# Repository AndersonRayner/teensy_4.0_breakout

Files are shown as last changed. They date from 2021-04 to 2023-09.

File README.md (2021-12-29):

# Teensy 4.0 Breakout
Breakout Board for the Teensy 4.0. The connectors are designed to match the Pixhawk standard connectors, making it easy to interface with different sensors.

Features:
- 6 - 36 V Input
- 2 x Serial ports
- 1 x SPI with 2x CS
- 2 x I2C Ports
- 3 x PWM / ADC

<p align="center">
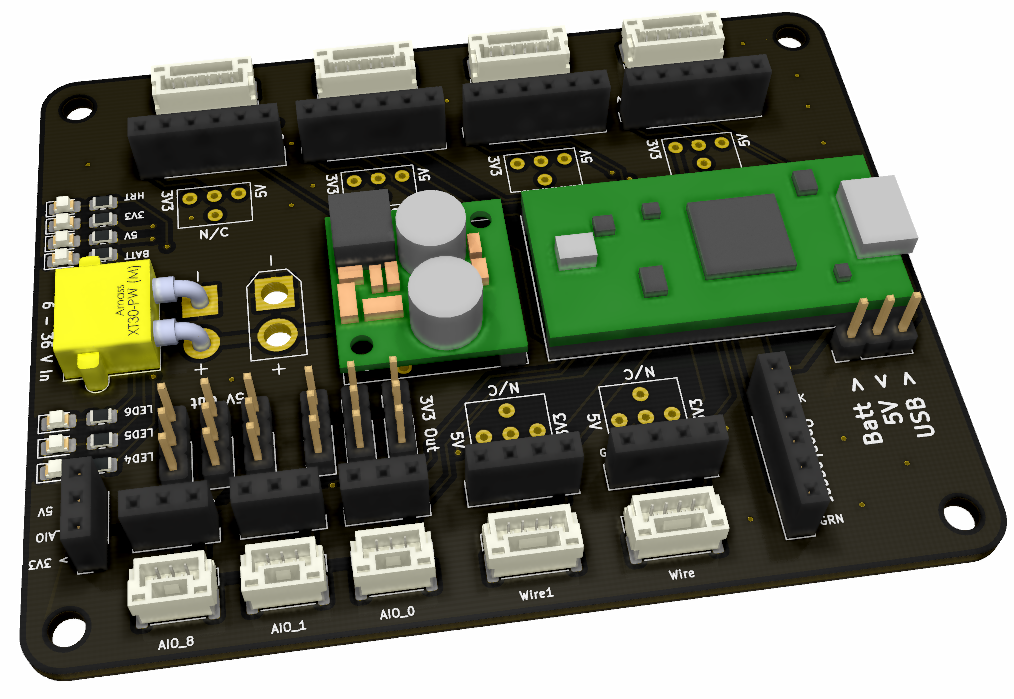
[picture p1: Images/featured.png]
  
</p>

Make sure to clone recursively!
```
git clone https://github.com/AndersonRayner/teensy_4.0_breakout.git --recursive
```

## Usage
- As the connectors are matching the Pixhawk standard, using the 0.1" headers means you can reverse plug! 
- Power for each of the output rails can be selected using the jumpers (between 3V3 and 5V)

## Contributions
As always, PRs are welcome!

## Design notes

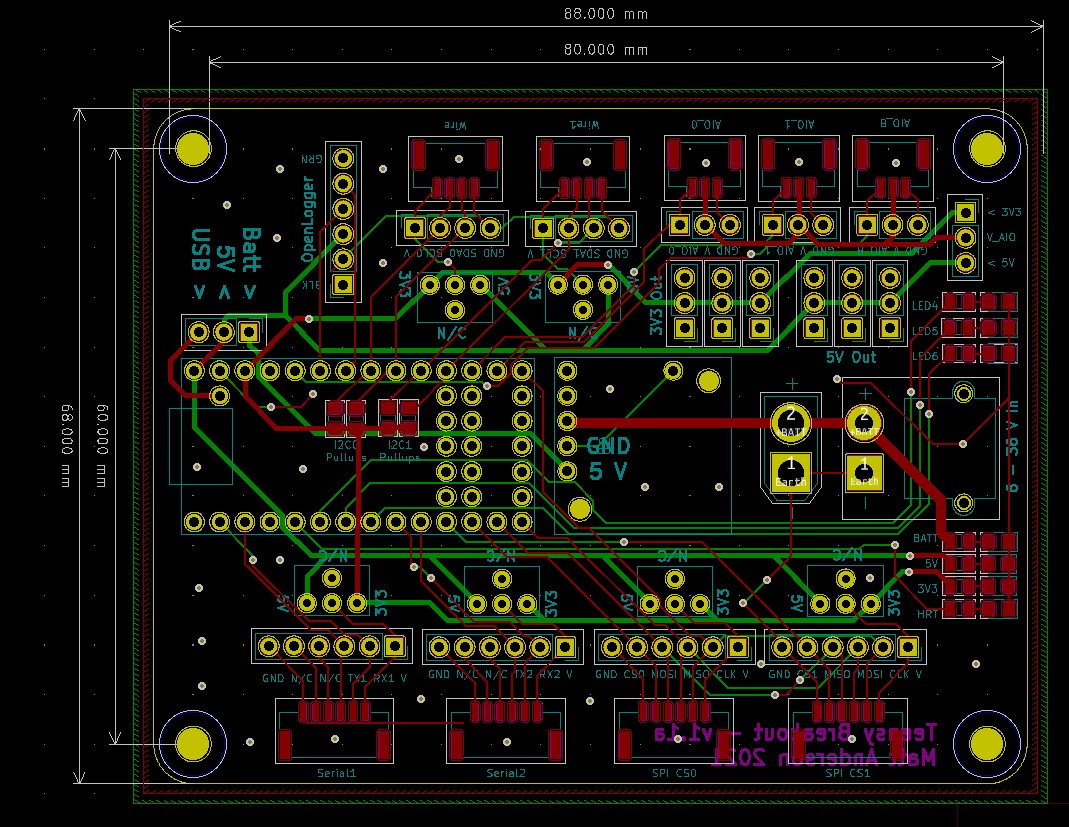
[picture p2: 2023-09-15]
PCB/schematics/pcb.jpg

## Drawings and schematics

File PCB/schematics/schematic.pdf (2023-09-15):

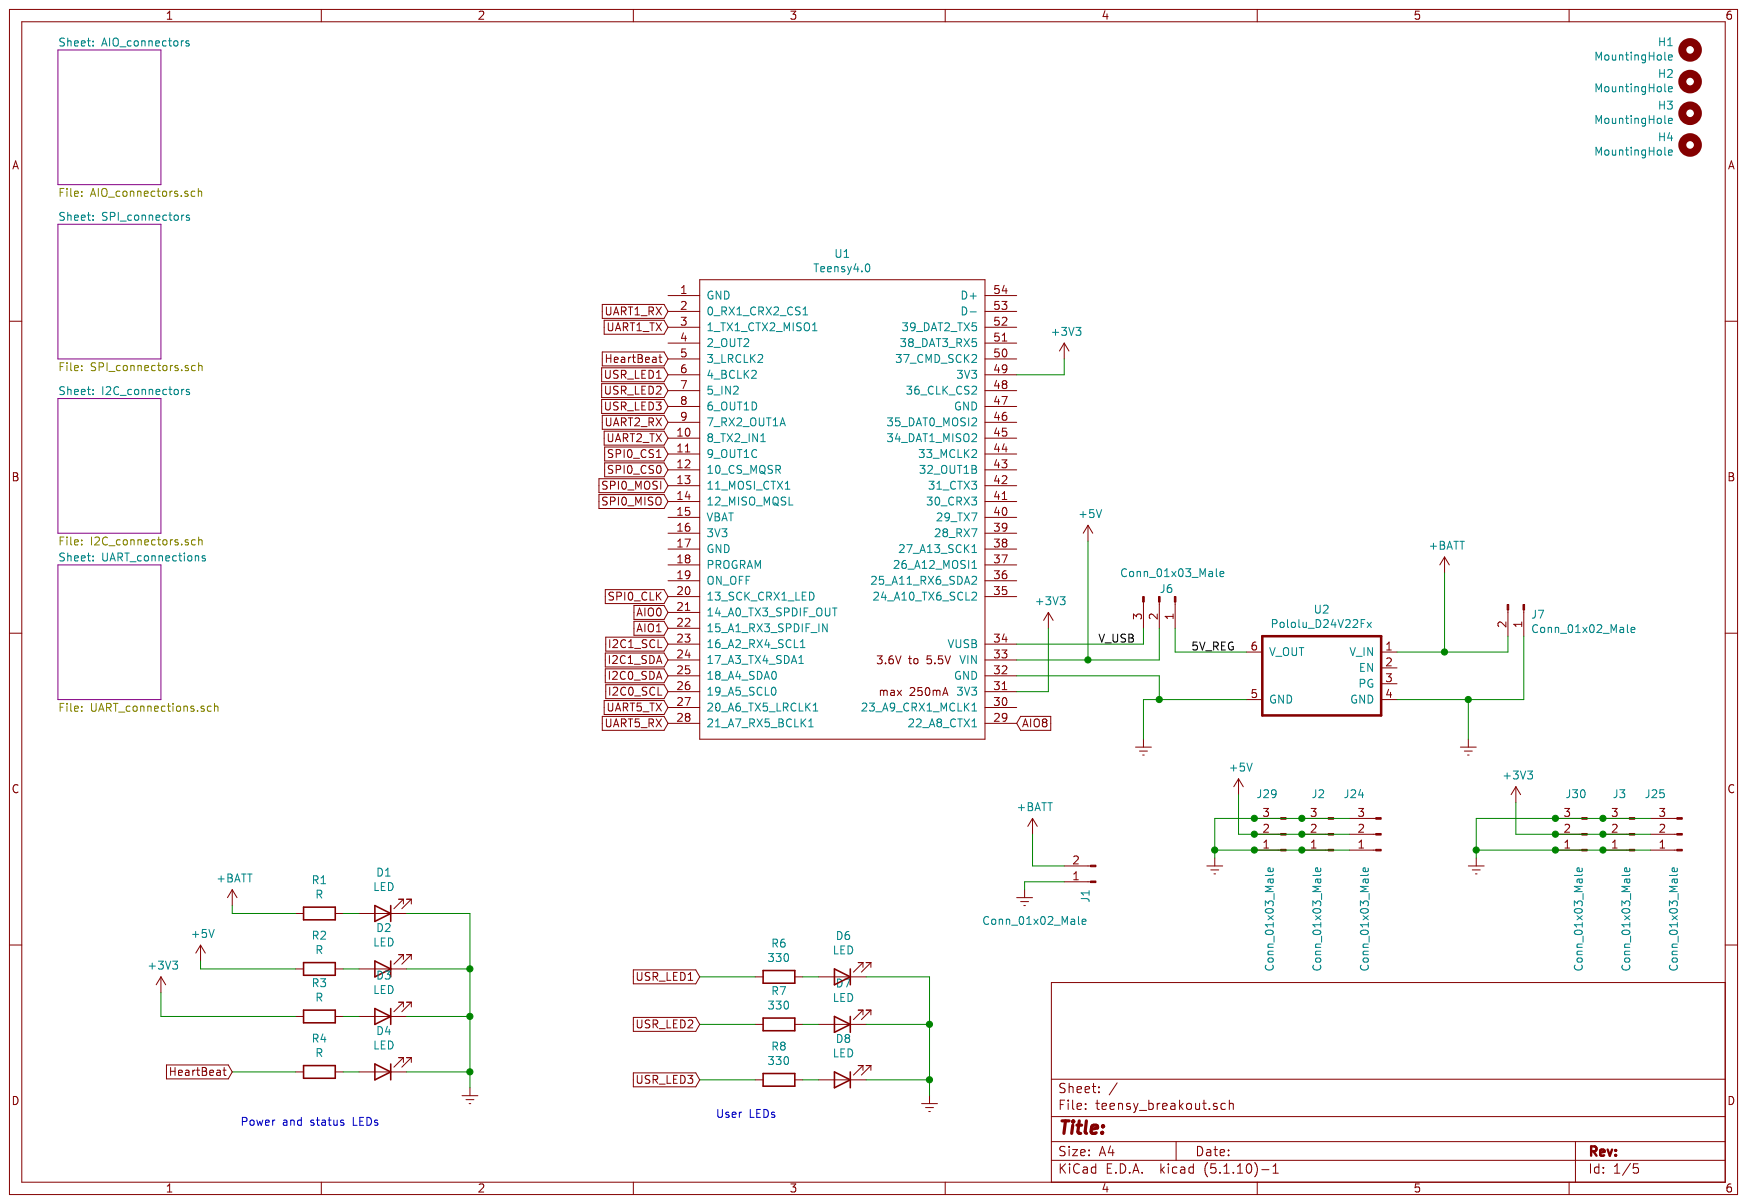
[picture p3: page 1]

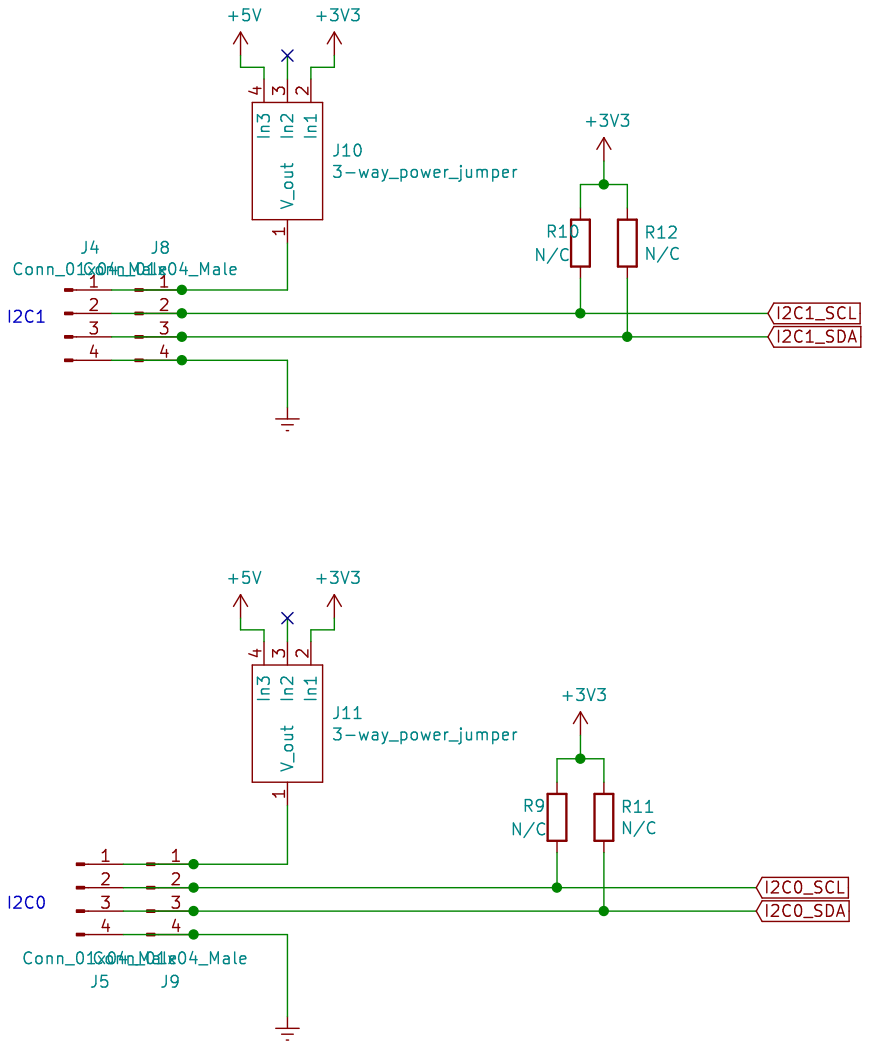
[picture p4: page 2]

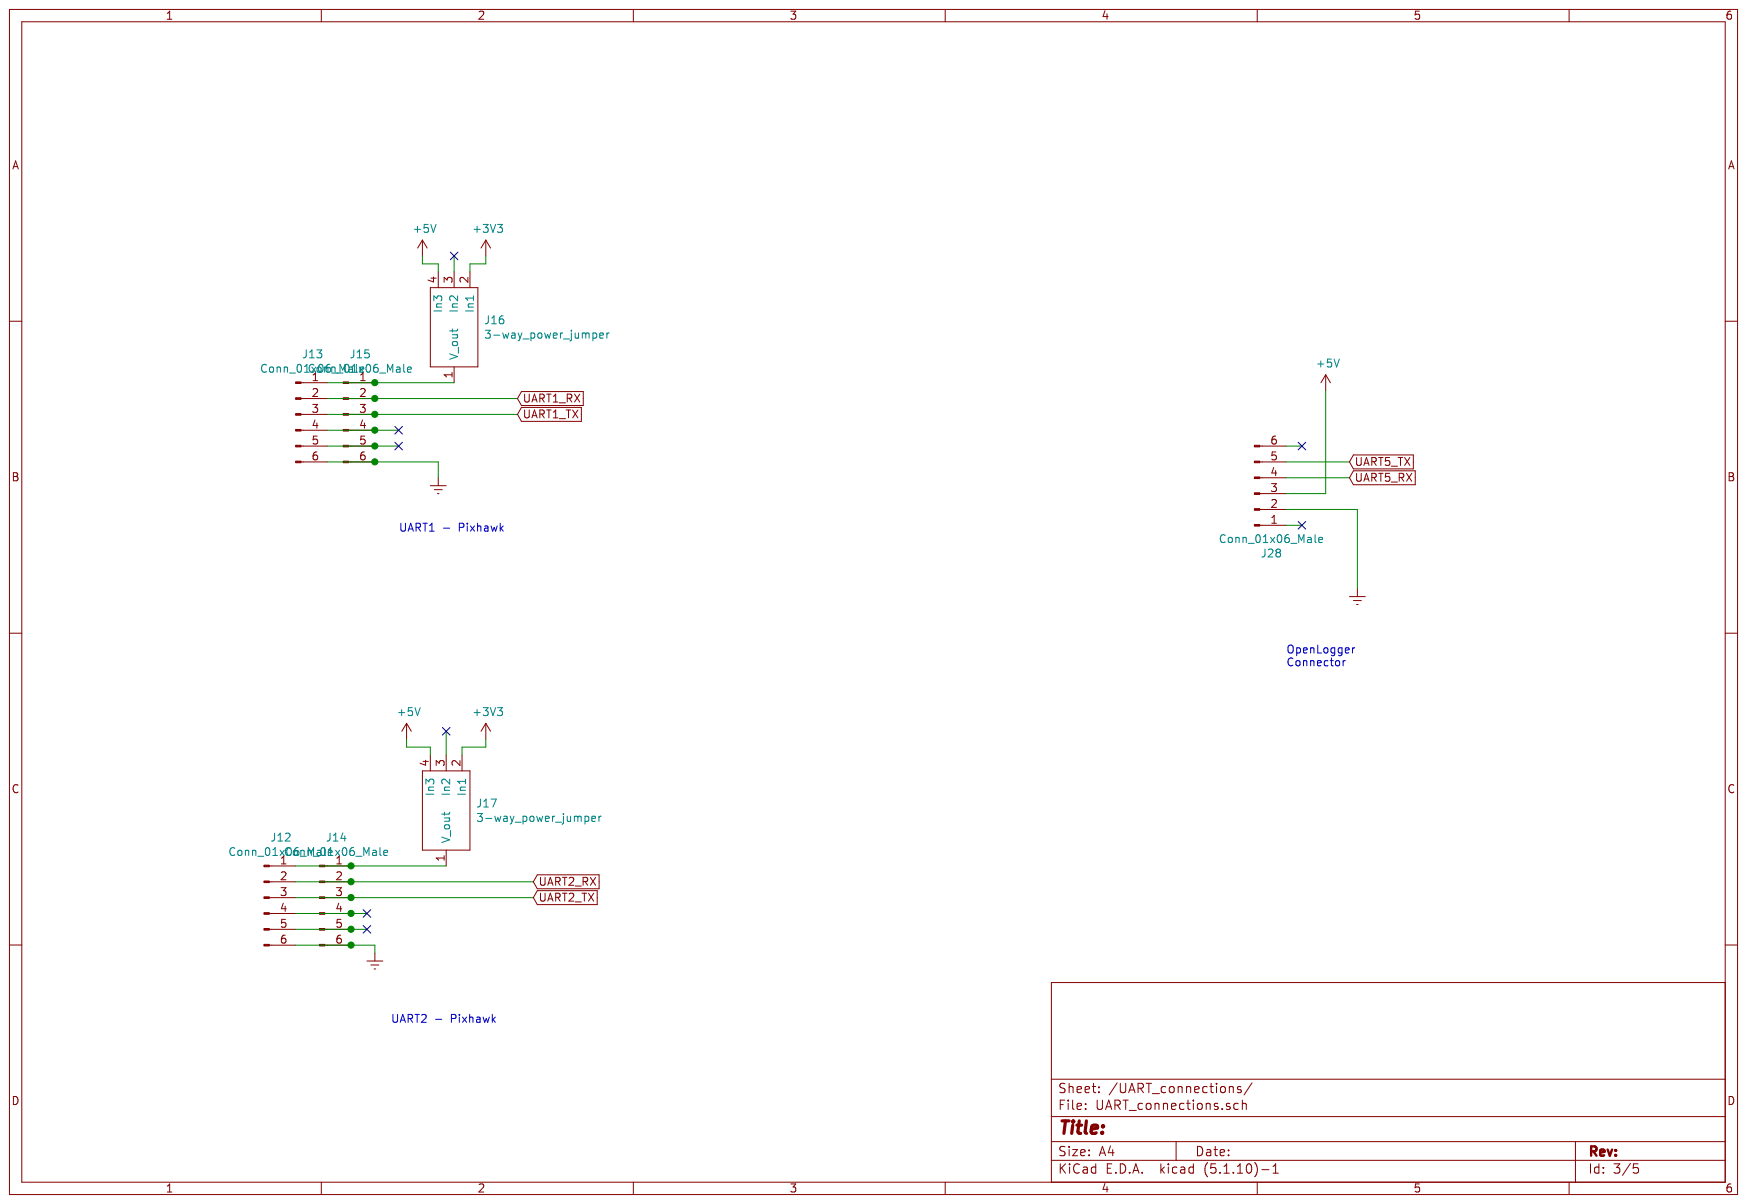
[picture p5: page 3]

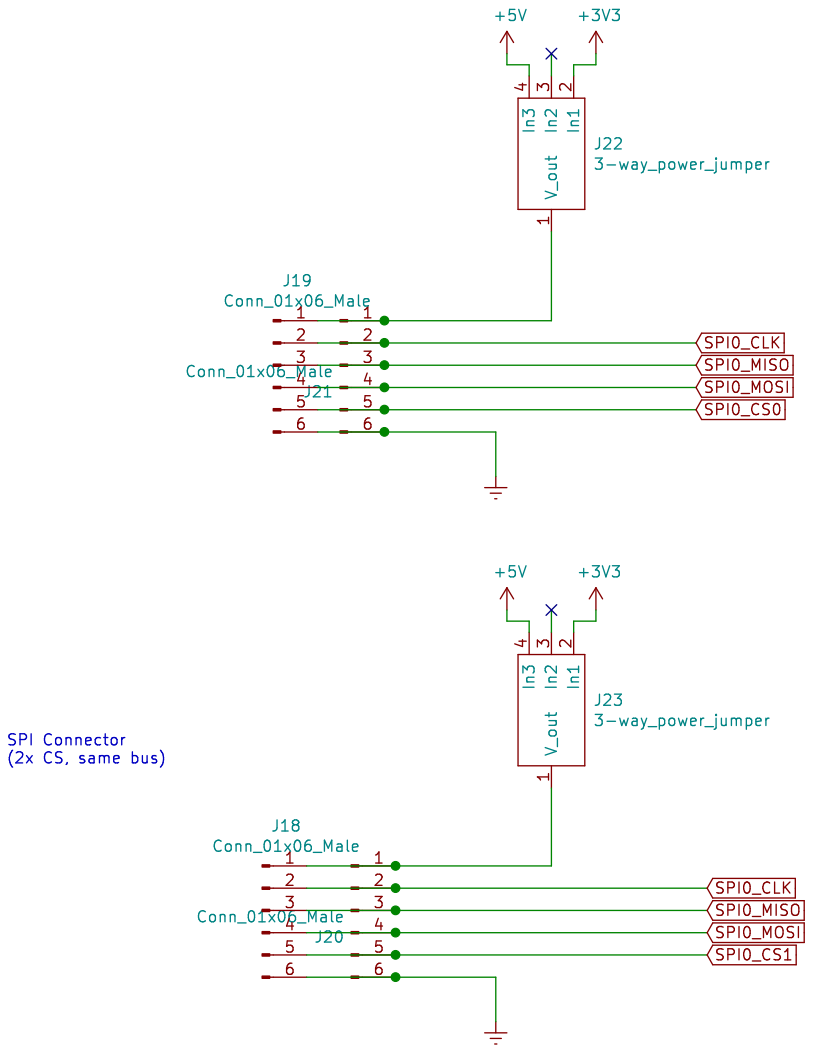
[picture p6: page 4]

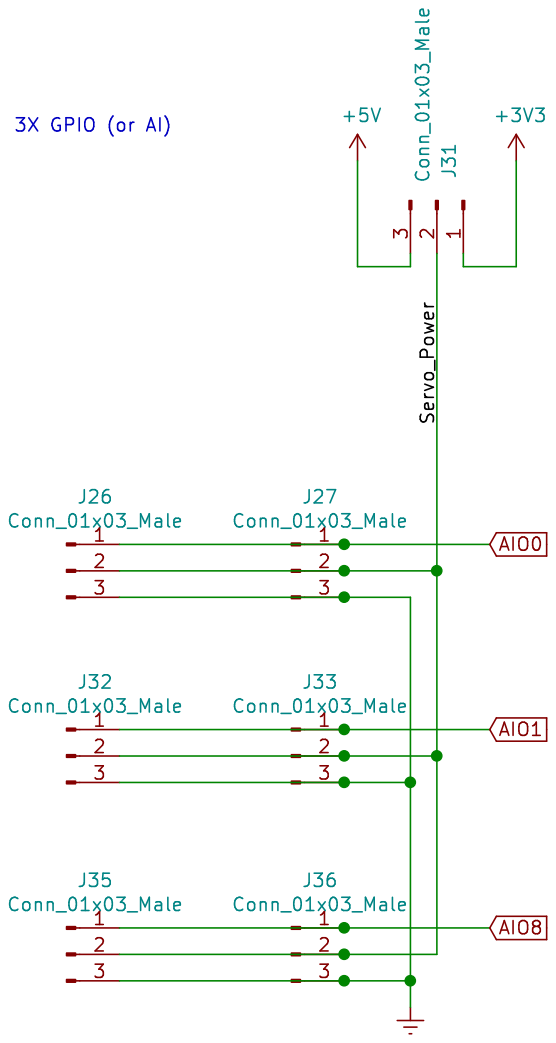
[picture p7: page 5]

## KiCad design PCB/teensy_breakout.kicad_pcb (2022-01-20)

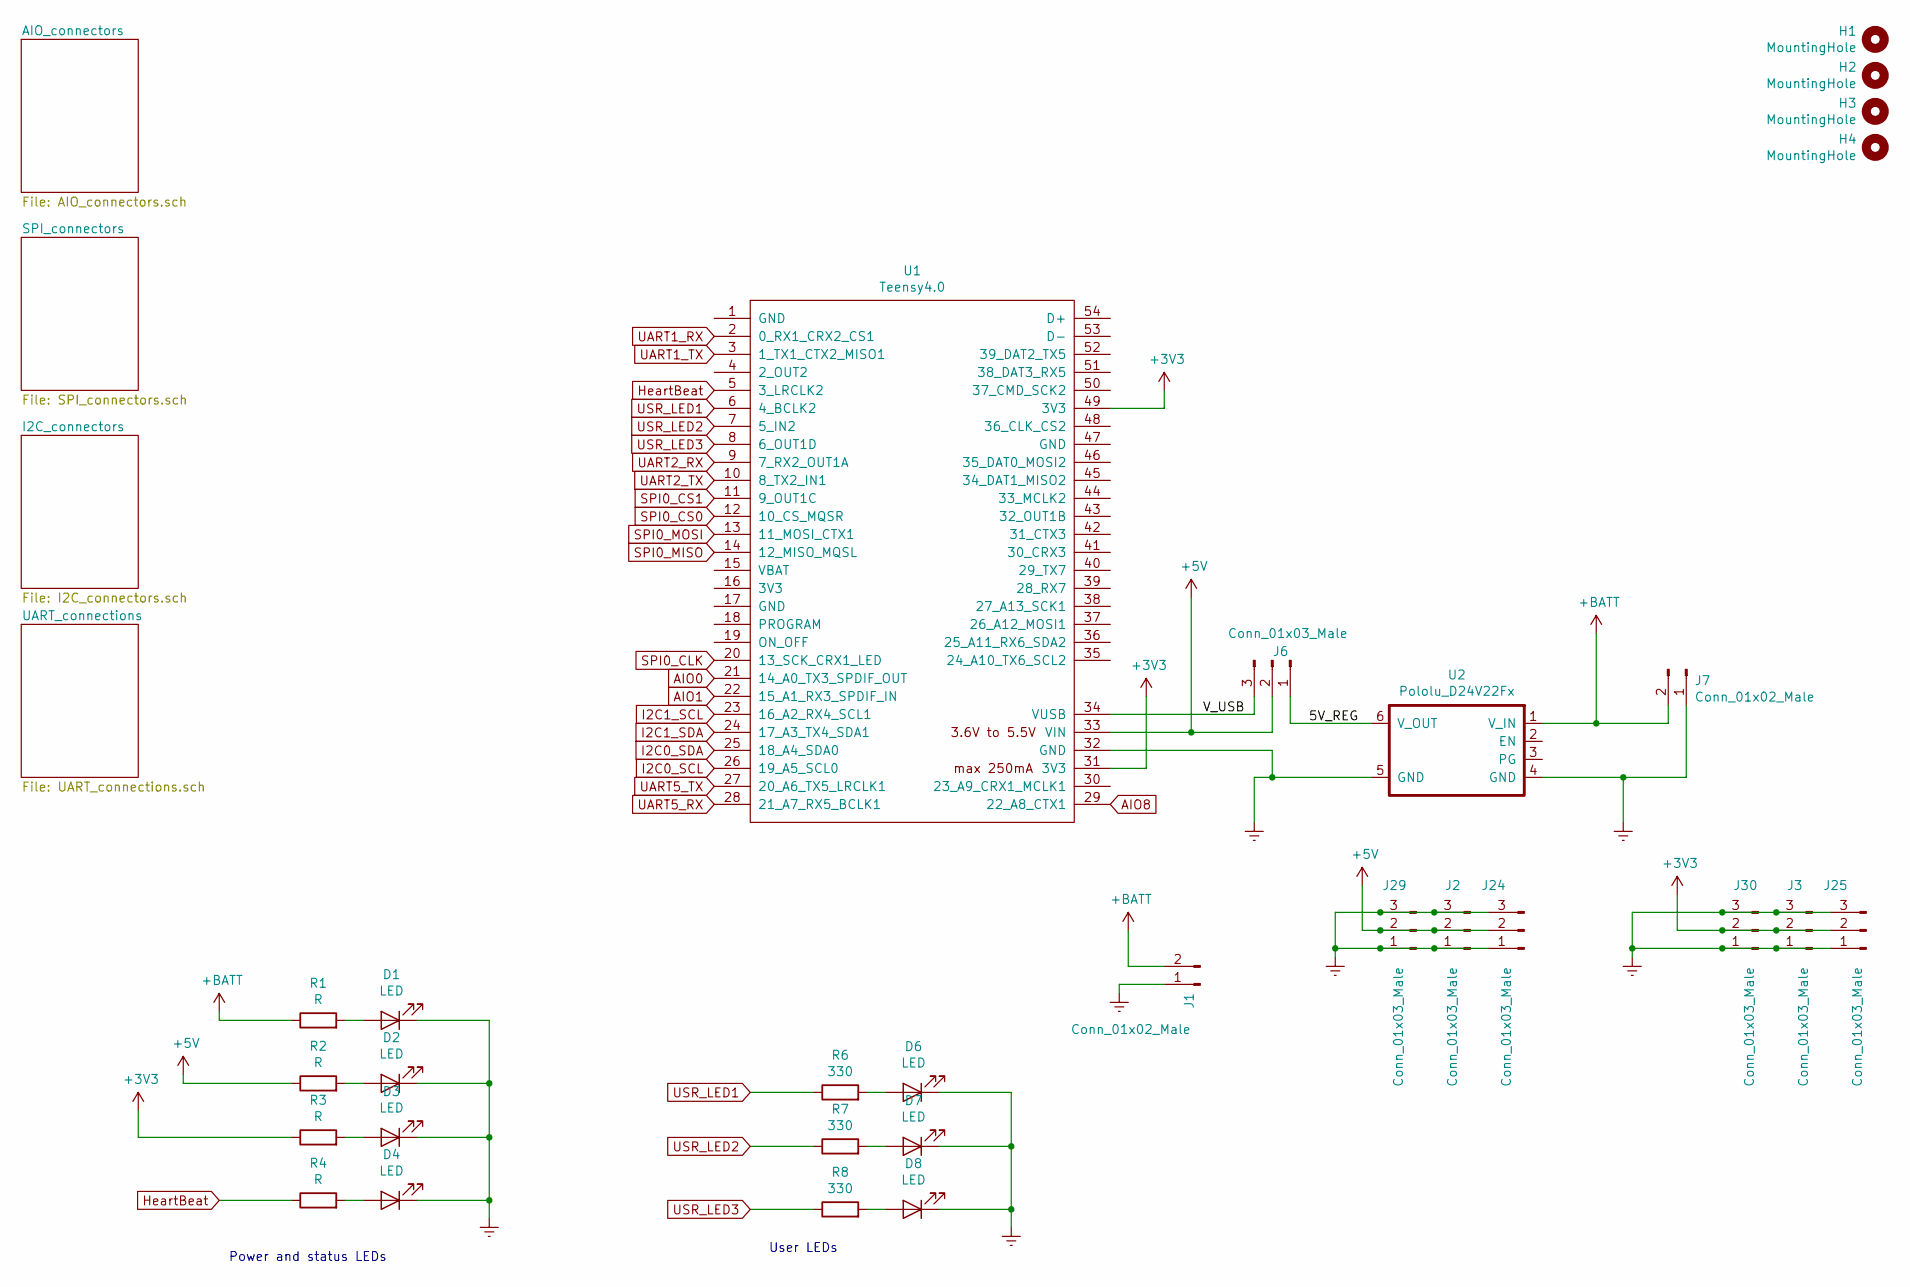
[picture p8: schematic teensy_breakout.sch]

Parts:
D1, D2, D3, D4, D6, D7, D8: LED; LED_0805_2012Metric_Pad1.15x1.40mm_HandSolder
H1, H2, H3, H4: MountingHole; MountingHole_3.2mm_M3
J1: Conn_01x02_Male; AMASS_XT30U-M_1x02_P5.0mm_Vertical
J2, J3, J6, J24, J25, J29, J30: Conn_01x03_Male; PinHeader_1x03_P2.54mm_Vertical
J7: Conn_01x02_Male; AMASS_XT30PW-M_1x02_P2.50mm_Horizontal
R1, R2, R3, R4: R; R_0805_2012Metric
R6, R7, R8: 330; R_0805_2012Metric
U1: Teensy4.0; Teensy40
U2: Pololu_D24V22Fx; Pololu_D24V22Fx_THT

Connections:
+3V3: J3.2, J25.2, J30.2, R3.1, U1.31 (3V3), U1.49 (3V3); also elsewhere on the board
+5V: J2.2, J6.2, J24.2, J29.2, R2.1, U1.33 (VIN); also elsewhere on the board
+BATT: J1.2, J7.2, R1.1, U2.1 (V_IN)
/5V_REG: J6.1, U2.6 (V_OUT)
/V_USB: J6.3, U1.34 (VUSB)
AIO0: U1.21 (14_A0_TX3_SPDIF_OUT); also elsewhere on the board
AIO1: U1.22 (15_A1_RX3_SPDIF_IN); also elsewhere on the board
AIO8: U1.29 (22_A8_CTX1); also elsewhere on the board
Earth: D1.1 (K), D2.1 (K), D3.1 (K), D4.1 (K), D6.1 (K), D7.1 (K), D8.1 (K), J1.1, J2.1, J2.3, J3.1, J3.3, J7.1, J24.1, J24.3, J25.1, J25.3, J29.1, J29.3, J30.1, J30.3, U1.32 (GND), U2.4 (GND), U2.5 (GND); also elsewhere on the board
HeartBeat: R4.1, U1.5 (3_LRCLK2)
I2C0_SCL: U1.26 (19_A5_SCL0); also elsewhere on the board
I2C0_SDA: U1.25 (18_A4_SDA0); also elsewhere on the board
I2C1_SCL: U1.23 (16_A2_RX4_SCL1); also elsewhere on the board
I2C1_SDA: U1.24 (17_A3_TX4_SDA1); also elsewhere on the board
unnamed: D1.2 (A), R1.2
unnamed: D2.2 (A), R2.2
unnamed: D3.2 (A), R3.2
unnamed: D4.2 (A), R4.2
unnamed: D6.2 (A), R6.2
unnamed: D7.2 (A), R7.2
unnamed: D8.2 (A), R8.2
SPI0_CLK: U1.20 (13_SCK_CRX1_LED); also elsewhere on the board
SPI0_CS0: U1.12 (10_CS_MQSR); also elsewhere on the board
SPI0_CS1: U1.11 (9_OUT1C); also elsewhere on the board
SPI0_MISO: U1.14 (12_MISO_MQSL); also elsewhere on the board
SPI0_MOSI: U1.13 (11_MOSI_CTX1); also elsewhere on the board
UART1_RX: U1.2 (0_RX1_CRX2_CS1); also elsewhere on the board
UART1_TX: U1.3 (1_TX1_CTX2_MISO1); also elsewhere on the board
UART2_RX: U1.9 (7_RX2_OUT1A); also elsewhere on the board
UART2_TX: U1.10 (8_TX2_IN1); also elsewhere on the board
UART5_RX: U1.28 (21_A7_RX5_BCLK1); also elsewhere on the board
UART5_TX: U1.27 (20_A6_TX5_LRCLK1); also elsewhere on the board
USR_LED1: R6.1, U1.6 (4_BCLK2)
USR_LED2: R7.1, U1.7 (5_IN2)
USR_LED3: R8.1, U1.8 (6_OUT1D)

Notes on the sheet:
Power and status LEDs
User LEDs

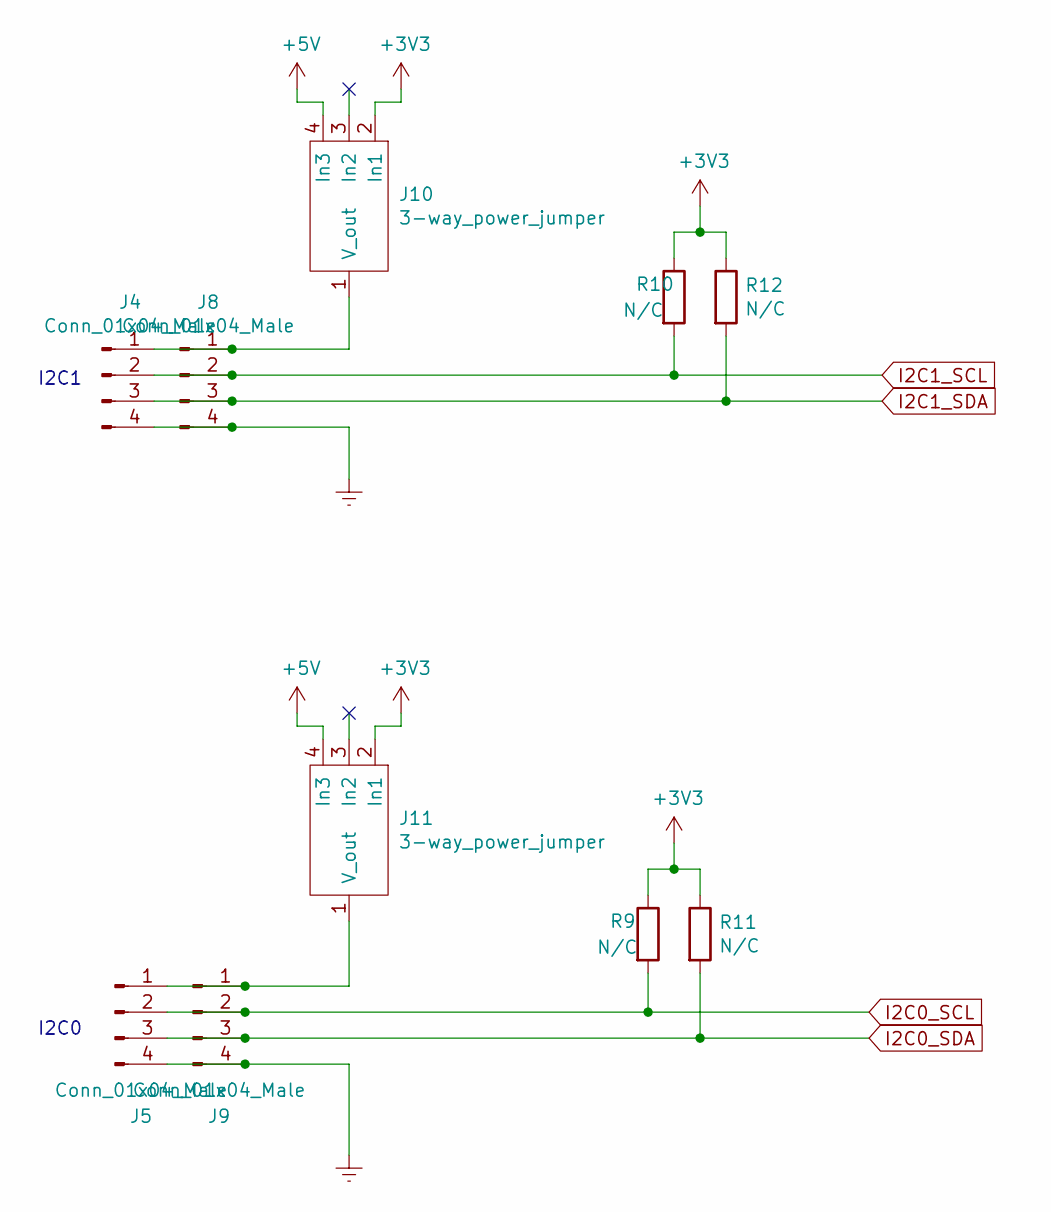
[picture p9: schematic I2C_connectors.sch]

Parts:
J4, J5: Conn_01x04_Male; PinSocket_1x04_P2.54mm_Vertical
J8, J9: Conn_01x04_Male; JST_GH_BM04B-GHS-TBT_1x04-1MP_P1.25mm_Vertical
J10, J11: 3-way_power_jumper
R9, R10, R11, R12: N/C; R_0805_2012Metric_Pad1.15x1.40mm_HandSolder

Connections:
+3V3: J10.2 (In1), J11.2 (In1), R9.1, R10.1, R11.1, R12.1; also elsewhere on the board
+5V: J10.4 (In3), J11.4 (In3); also elsewhere on the board
Earth: J4.4, J5.4, J8.4, J9.4; also elsewhere on the board
I2C0_SCL: J5.2, J9.2, R9.2; also elsewhere on the board
I2C0_SDA: J5.3, J9.3, R11.2; also elsewhere on the board
I2C1_SCL: J4.2, J8.2, R10.2; also elsewhere on the board
I2C1_SDA: J4.3, J8.3, R12.2; also elsewhere on the board
unnamed: J4.1, J8.1, J10.1 (V_out)
unnamed: J5.1, J9.1, J11.1 (V_out)

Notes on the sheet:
I2C1
I2C0

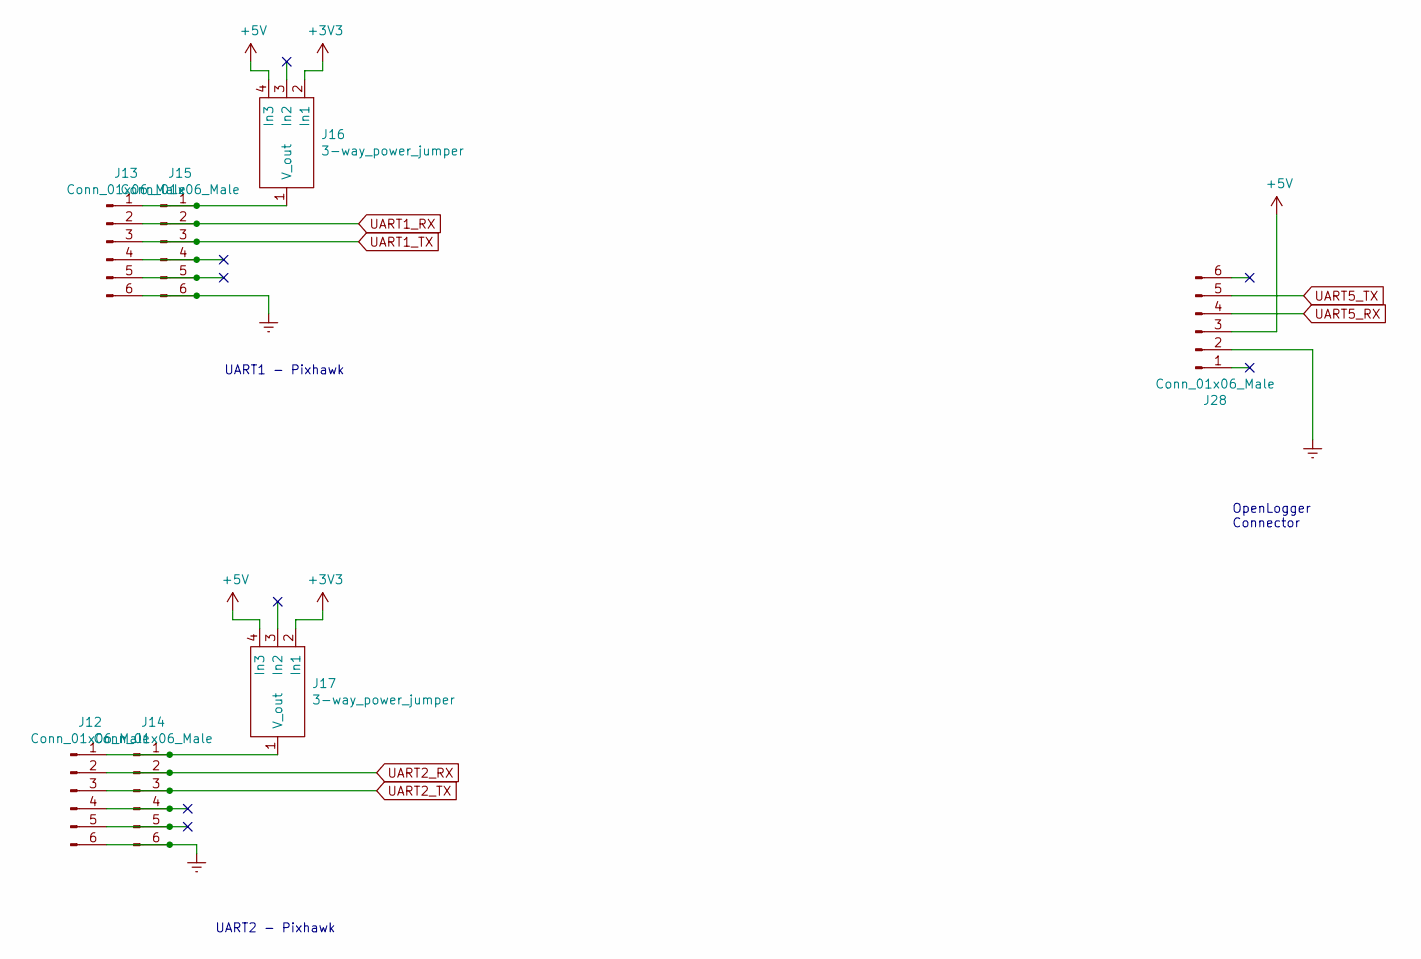
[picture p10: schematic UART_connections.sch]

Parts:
J12, J13, J28: Conn_01x06_Male; PinSocket_1x06_P2.54mm_Vertical
J14, J15: Conn_01x06_Male; JST_GH_BM06B-GHS-TBT_1x06-1MP_P1.25mm_Vertical
J16, J17: 3-way_power_jumper

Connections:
+3V3: J16.2 (In1), J17.2 (In1); also elsewhere on the board
+5V: J16.4 (In3), J17.4 (In3), J28.3; also elsewhere on the board
Earth: J12.6, J13.6, J14.6, J15.6, J28.2; also elsewhere on the board
unnamed: J12.1, J14.1, J17.1 (V_out)
unnamed: J12.4, J14.4
unnamed: J12.5, J14.5
unnamed: J13.1, J15.1, J16.1 (V_out)
unnamed: J13.4, J15.4
unnamed: J13.5, J15.5
UART1_RX: J13.2, J15.2; also elsewhere on the board
UART1_TX: J13.3, J15.3; also elsewhere on the board
UART2_RX: J12.2, J14.2; also elsewhere on the board
UART2_TX: J12.3, J14.3; also elsewhere on the board
UART5_RX: J28.4; also elsewhere on the board
UART5_TX: J28.5; also elsewhere on the board

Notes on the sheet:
UART2 - Pixhawk
UART1 - Pixhawk
OpenLogger Connector

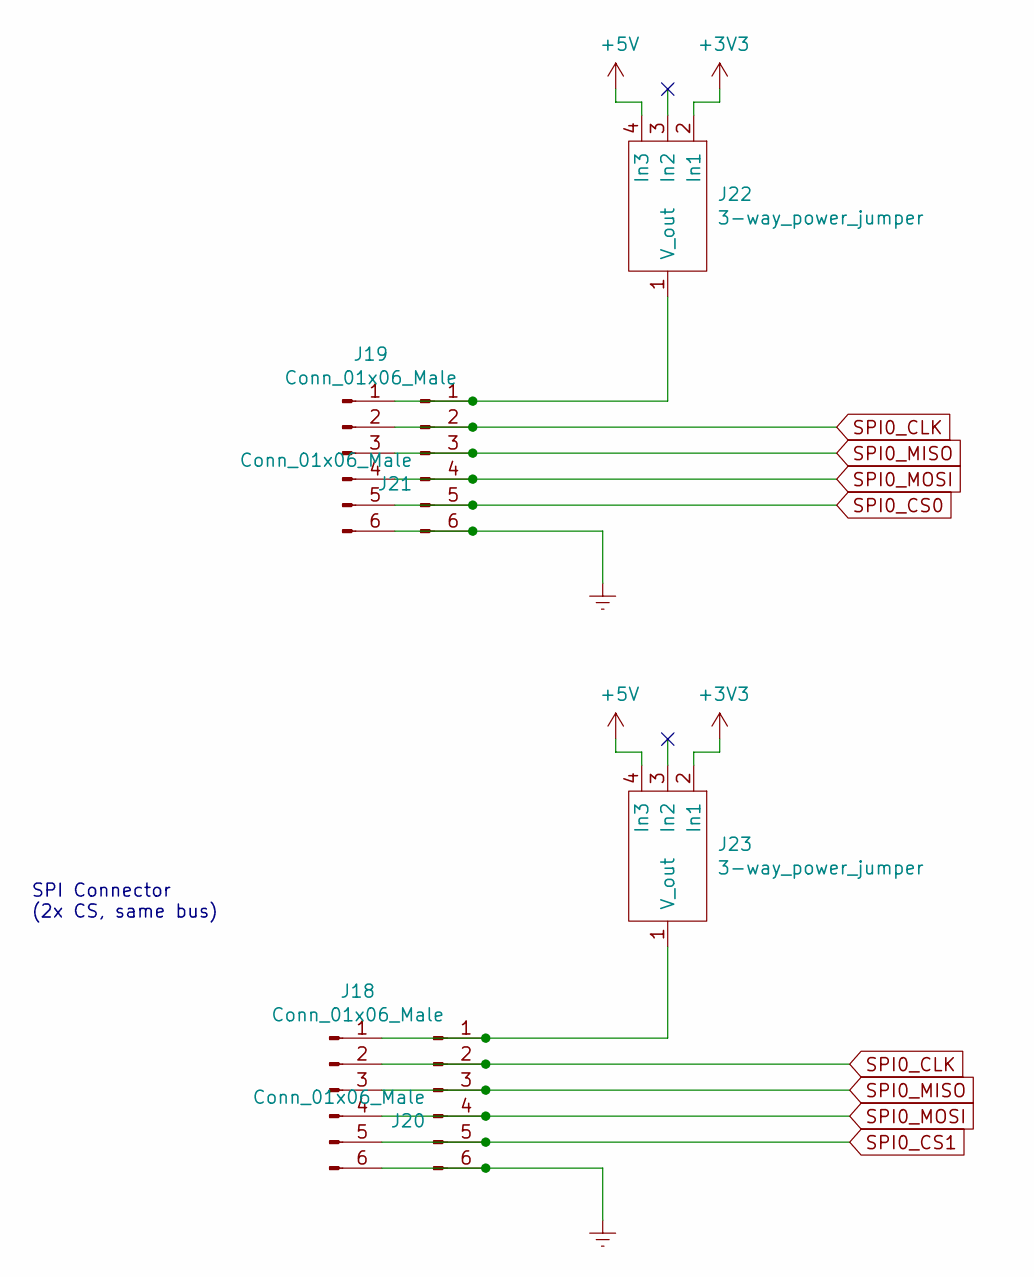
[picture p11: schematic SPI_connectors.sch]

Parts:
J18, J19: Conn_01x06_Male; PinSocket_1x06_P2.54mm_Vertical
J20, J21: Conn_01x06_Male; JST_GH_BM06B-GHS-TBT_1x06-1MP_P1.25mm_Vertical
J22, J23: 3-way_power_jumper

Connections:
+3V3: J22.2 (In1), J23.2 (In1); also elsewhere on the board
+5V: J22.4 (In3), J23.4 (In3); also elsewhere on the board
Earth: J18.6, J19.6, J20.6, J21.6; also elsewhere on the board
unnamed: J18.1, J20.1, J23.1 (V_out)
unnamed: J19.1, J21.1, J22.1 (V_out)
SPI0_CLK: J18.2, J19.2, J20.2, J21.2; also elsewhere on the board
SPI0_CS0: J19.5, J21.5; also elsewhere on the board
SPI0_CS1: J18.5, J20.5; also elsewhere on the board
SPI0_MISO: J18.3, J19.3, J20.3, J21.3; also elsewhere on the board
SPI0_MOSI: J18.4, J19.4, J20.4, J21.4; also elsewhere on the board

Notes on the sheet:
SPI Connector (2x CS, same bus)

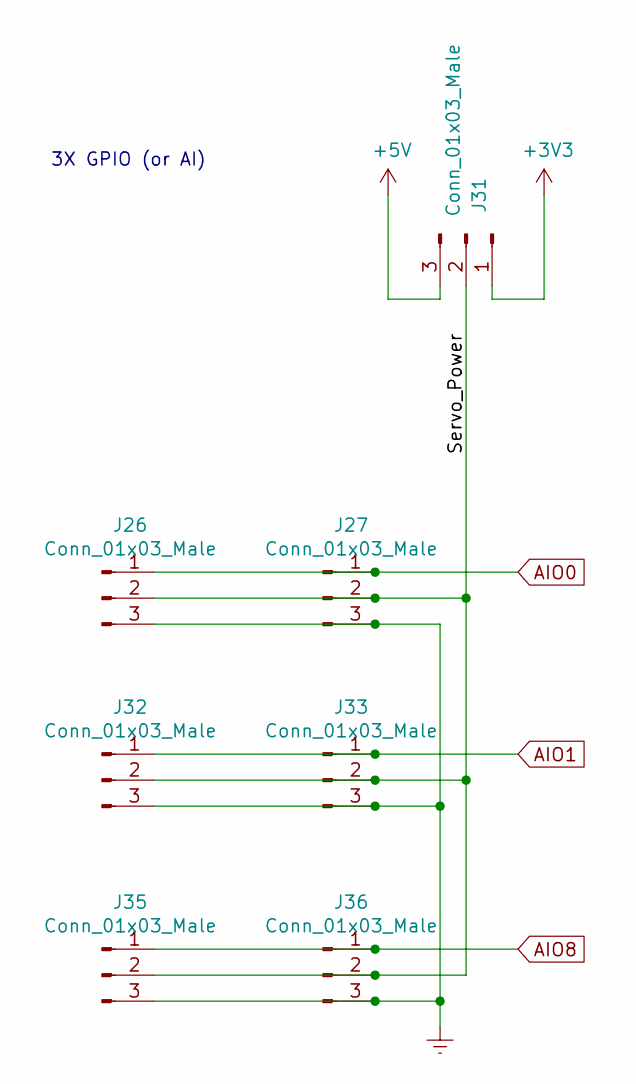
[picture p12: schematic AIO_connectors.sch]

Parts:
J26, J31, J32, J35: Conn_01x03_Male; PinSocket_1x03_P2.54mm_Vertical
J27, J33, J36: Conn_01x03_Male; JST_GH_BM03B-GHS-TBT_1x03-1MP_P1.25mm_Vertical

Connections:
+3V3: J31.1; also elsewhere on the board
+5V: J31.3; also elsewhere on the board
/AIO_connectors/Servo_Power: J26.2, J27.2, J31.2, J32.2, J33.2, J35.2, J36.2
AIO0: J26.1, J27.1; also elsewhere on the board
AIO1: J32.1, J33.1; also elsewhere on the board
AIO8: J35.1, J36.1; also elsewhere on the board
Earth: J26.3, J27.3, J32.3, J33.3, J35.3, J36.3; also elsewhere on the board

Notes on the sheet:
3X GPIO (or AI)

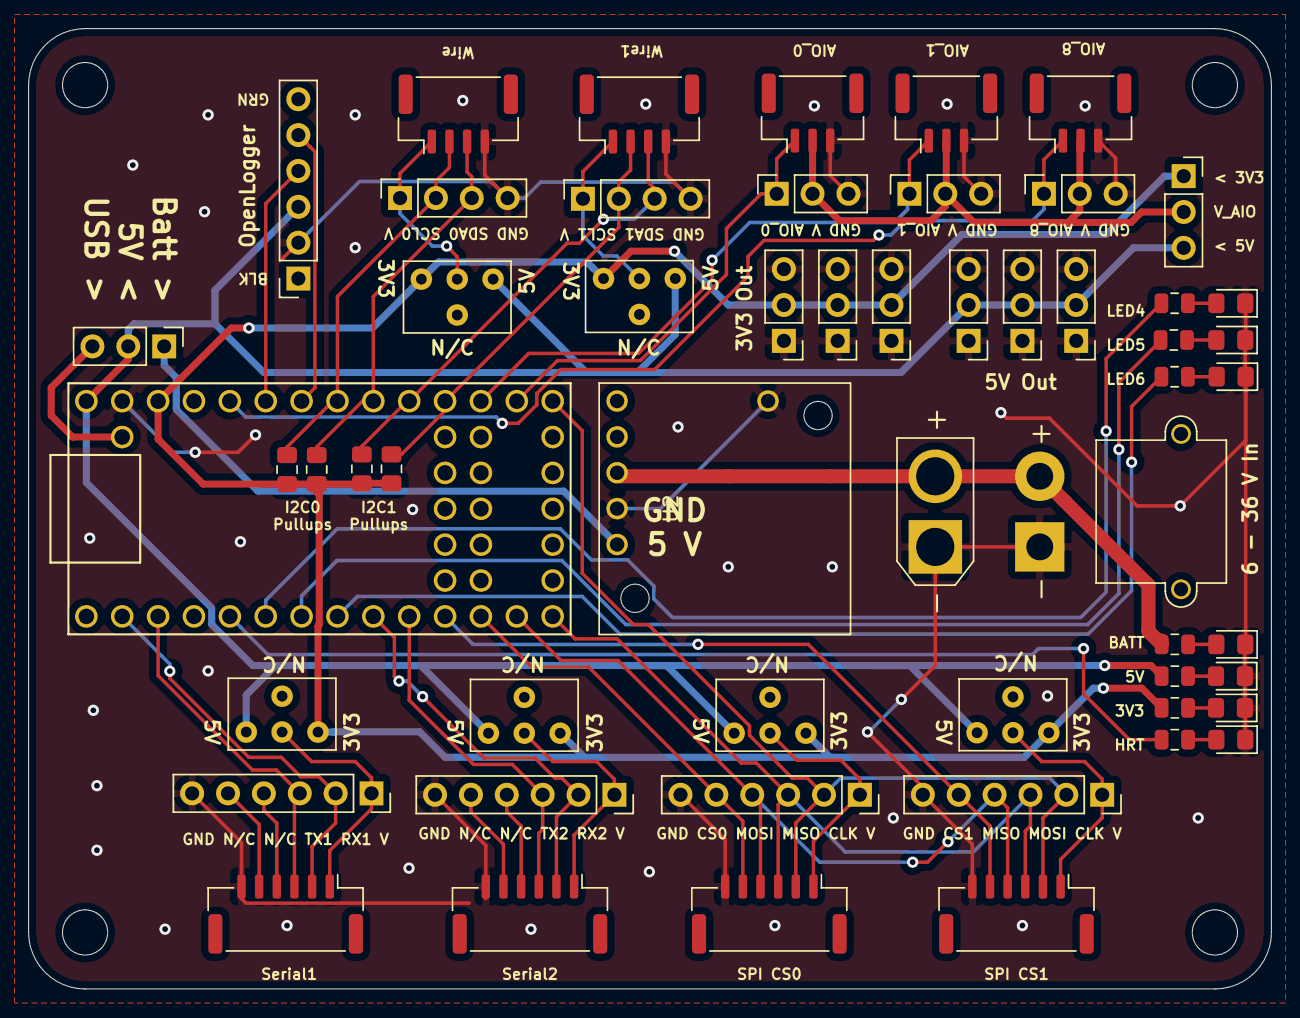
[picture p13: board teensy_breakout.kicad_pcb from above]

Board: 2 copper layers, 88.0 x 68.0 mm, 59 parts (0 on the bottom side), 46 nets.

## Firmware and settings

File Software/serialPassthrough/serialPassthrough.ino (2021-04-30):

// Script for serial pass through
#define LED_PIN 3
#define LED_USR1 4
#define LED_USR2 5

void setup() {
  // LEDs
  pinMode(LED_PIN, OUTPUT);
  pinMode(LED_USR1, OUTPUT);
  pinMode(LED_USR2, OUTPUT);

  // Serial Ports
  Serial.begin(115200);  // USB Serial
  Serial1.begin(57600); // Hardware Serial

}

void loop() {
  unsigned long loop_start = millis();

  digitalWrite(LED_PIN, !digitalRead(LED_PIN));

  do {
    // Transfer any data from USB (Serial) <> Hardware Serial
    while (Serial.available()) {
      //char a = Serial.read();
      Serial1.print((char) Serial.read());
      digitalWrite(LED_USR1, !digitalRead(LED_USR1));
    }

    while (Serial1.available()) {
      Serial.print((char) Serial1.read());
      digitalWrite(LED_USR2, !digitalRead(LED_USR2));
    }

  } while (millis() < loop_start+500);

}

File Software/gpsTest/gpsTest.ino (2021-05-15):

// Example script of streaming GPS data from Serial1.
// Uses the TinyGPS++ library
//
// *** Must be compiled with "Dual Serial" option ***
//

#define LED_PIN 3
#define LED_USR1 4
#define LED_USR2 5
#define LED_USR3 6

#define GPS_SERIAL Serial1

#include "TinyGPSPlus/src/TinyGPS++.cpp"
TinyGPSPlus gps;

void setup() {
  // LEDs
  pinMode(LED_PIN, OUTPUT);
  pinMode(LED_USR1, OUTPUT);
  pinMode(LED_USR2, OUTPUT);
  pinMode(LED_USR3, OUTPUT);

  // Serial Ports
  Serial.begin(115200);   // USB Serial (Info)
  SerialUSB1.begin(115200);  // USB Serial (Debug)
  GPS_SERIAL.begin(9600); // GPS Port

}

void loop() {
  
  unsigned long loop_start = millis();
  char rx;
  char buf[50];
  static bool home_saved = false;
  static TinyGPSLocation home_pos;
  static double home_alt;

  // Toggle and LED so we know things are alive
  digitalWrite(LED_PIN, !digitalRead(LED_PIN));

  while (millis() < loop_start + 500) {
    
    // Transfer any data from USB (Serial) > Serial 1
    while (Serial.available()) {
      GPS_SERIAL.write(Serial.read());
      digitalWrite(LED_USR1, !digitalRead(LED_USR1));
    }

    // Read in all the data from the GPS
    while (GPS_SERIAL.available()) {
      // Read from the serial port
      rx = GPS_SERIAL.read();

      // Echo information received to the second serial port
      SerialUSB1.write(rx);

      // Send to the GPS encoder
      gps.encode(rx);

      // Update LED
      digitalWrite(LED_USR2, !digitalRead(LED_USR2));

    }

    // Print out the current location
    if (gps.location.isUpdated()) {
      
      // Save the home location
      if (!home_saved) {
        if (gps.altitude.isValid() && gps.location.isValid()) {
          home_pos = gps.location;
          home_alt = gps.altitude.meters();
          home_saved = true;
        }
      }

      // Print the updated location
      sprintf(buf, "Lat: %.9f [ deg ], Lon: %.9f [ deg ], Alt: %.3f [ m ]\n", gps.location.lat(), gps.location.lng(), gps.altitude.meters());
      Serial.print(buf);

      // Print the NED relative to home
      double N, E, U;
      latlon_to_NE(gps.location.lat(), gps.location.lng(), home_pos.lat(), home_pos.lng(), &N, &E);
      U = gps.altitude.meters() - home_alt;
      
      sprintf(buf, "\tN: %.2f [ m ], E: %.2f [ m ], U: %.2f [ m ]\n", N, E, U);
      Serial.print(buf);

    }

  }

}

void latlon_to_NE(double lat, double lon, double lat0, double lon0, double *N, double *E) {
  
  // Convert lat/lon to NE
  static constexpr double LOCATION_SCALING_FACTOR = 111318.84502145034;  // deg to m

  *N = (lat-lat0) * LOCATION_SCALING_FACTOR;
  *E = (lon-lon0) * LOCATION_SCALING_FACTOR * max(cos(lat0*DEG_TO_RAD),0.01);

  return;

}

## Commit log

2021-05-15 Fixed the GPS example
    [gpsTest.ino]
2021-12-29 Fixing all the paths
    [I2C_connectors.sch, SPI_connectors.sch, UART_connections.sch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]
2022-01-20 Fixed the labelling on the SPI bus
    [teensy_breakout-B_Cu.gbl, teensy_breakout-B_Mask.gbs, teensy_breakout-B_Paste.gbp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]
2022-01-20 Updated the version number
    [teensy_breakout-B_Cu.gbl, teensy_breakout-B_Mask.gbs, teensy_breakout-B_Paste.gbp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]
2023-09-15 Updated to add PDF and CAN test script
    [teensy_breakout-B_Cu.gbl, teensy_breakout-B_Mask.gbs, teensy_breakout-B_Paste.gbp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]
